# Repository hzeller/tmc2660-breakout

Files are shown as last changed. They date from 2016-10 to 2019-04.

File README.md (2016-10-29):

Breakout board for TMC2660
==========================

Breakout board with just the bare chip and necessary components around for
the [TMC2660][tmc2660-product] 2.8A stepper driver chip.
Detailed description found in the [datasheet][tmc2660-datasheet].



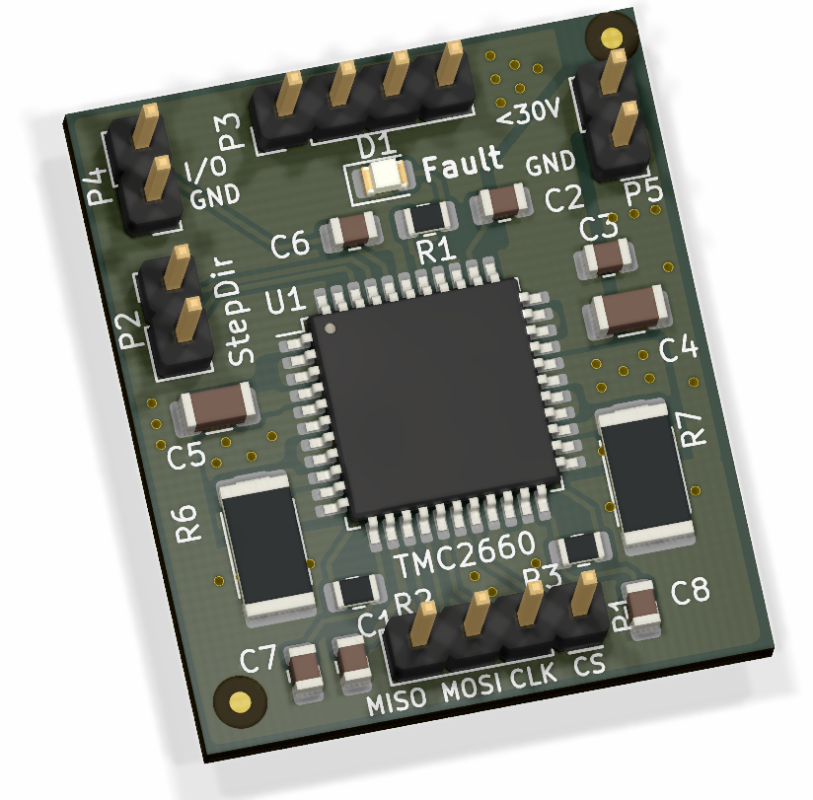
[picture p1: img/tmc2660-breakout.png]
Rendering


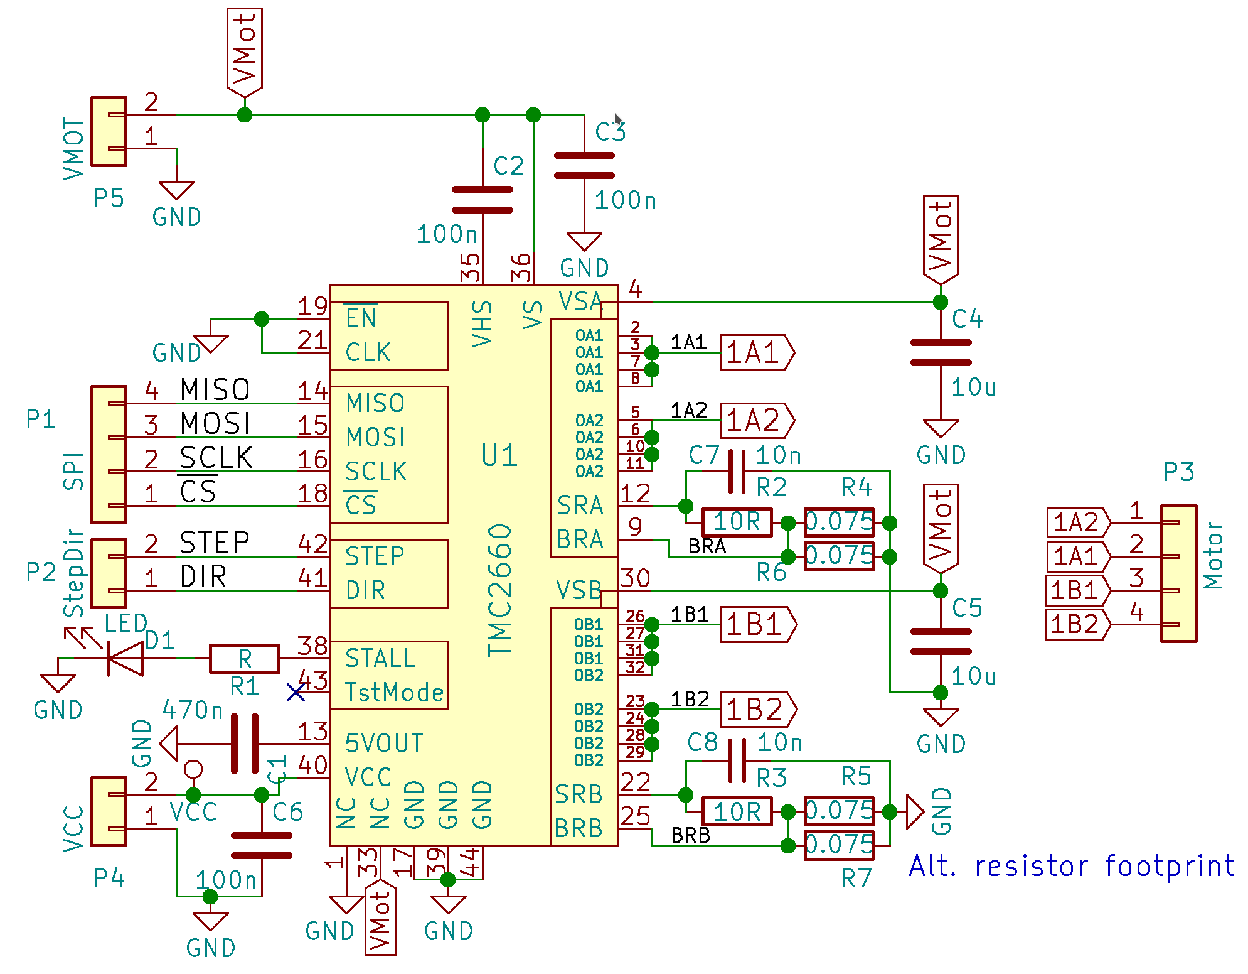
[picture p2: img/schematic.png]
Breakout schematic


[tmc2660-product]: http://www.trinamic.com/products/integrated-circuits/stepper-power-driver/tmc2660
[tmc2660-datasheet]: http://www.trinamic.com/_scripts/download.php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
[rendering]: ./img/tmc2660-breakout.png
[schematic]: ./img/schematic.png

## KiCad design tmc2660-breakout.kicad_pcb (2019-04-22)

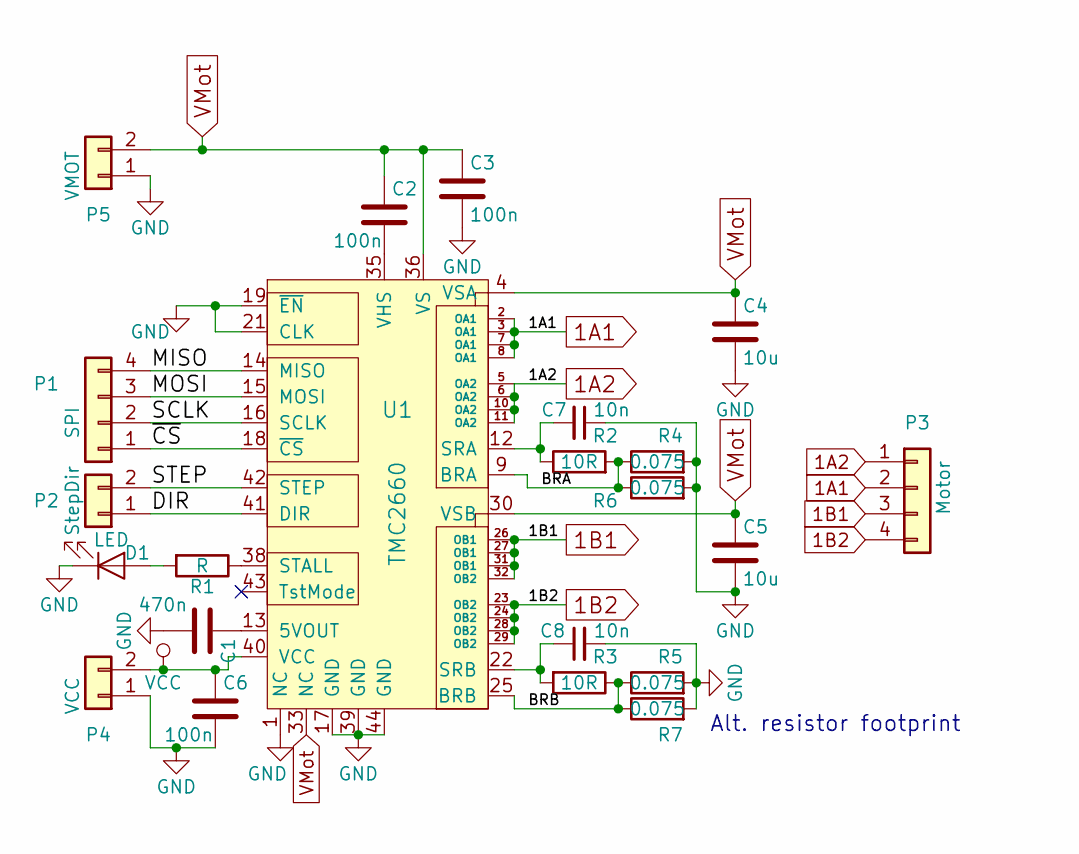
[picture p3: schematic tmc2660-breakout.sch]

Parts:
C1: 470n; C_0805_2012Metric
C2, C3, C6: 100n; C_0805_2012Metric
C4, C5: 10u; C_1206_3216Metric
C7, C8: 10n; C_0805_2012Metric
D1: LED; LED_0805_2012Metric
P1: SPI; PinHeader_1x04_P2.54mm_Vertical
P2: StepDir; PinHeader_1x02_P2.54mm_Vertical
P3: Motor; PinHeader_1x04_P2.54mm_Vertical
P4: VCC; PinHeader_1x02_P2.54mm_Vertical
P5: VMOT; PinHeader_1x02_P2.54mm_Vertical
R1: R; R_0805_2012Metric
R2, R3: 10R; R_0805_2012Metric
R4, R5: 0.075; R_1206_3216Metric
R6, R7: 0.075; R_2512_6332Metric
U1: TMC2660; LQFP-44_10x10mm_P0.8mm

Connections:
1A1: P3.2, U1.2 (OA1), U1.3 (OA1), U1.7 (OA1), U1.8 (OA1)
1A2: P3.1, U1.5 (OA2), U1.6 (OA2), U1.10 (OA2), U1.11 (OA2)
1B1: P3.3, U1.26 (OB1), U1.27 (OB1), U1.31 (OB1), U1.32 (OB2)
1B2: P3.4, U1.23 (OB2), U1.24 (OB2), U1.28 (OB2), U1.29 (OB2)
/BRA: R2.2, R4.1, R6.1, U1.9 (BRA)
/BRB: R3.1, R5.1, R7.1, U1.25 (BRB)
/DIR: P2.1, U1.41 (DIR)
/MISO: P1.4, U1.14 (MISO)
/MOSI: P1.3, U1.15 (MOSI)
/SCLK: P1.2, U1.16 (SCLK)
/STEP: P2.2, U1.42 (STEP)
/~CS: P1.1, U1.18 (~CS)
GND: C1.2, C3.2, C4.2, C5.2, C6.2, C7.1, C8.2, D1.1 (K), P4.1, P5.1, R4.2, R5.2, R6.2, R7.2, U1.1 (NC), U1.17 (GND), U1.19 (~EN), U1.21 (CLK), U1.39 (GND), U1.44 (GND)
unnamed: C1.1, U1.13 (5VOUT)
unnamed: C2.2, U1.35 (VHS)
unnamed: C7.2, R2.1, U1.12 (SRA)
unnamed: C8.1, R3.2, U1.22 (SRB)
unnamed: D1.2 (A), R1.2
unnamed: R1.1, U1.38 (STALL)
VCC: C6.1, P4.2, U1.40 (VCC)
VMot: C2.1, C3.1, C4.1, C5.1, P5.2, U1.4 (VSA), U1.30 (VSB), U1.33 (NC), U1.36 (VS)

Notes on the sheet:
Alt. resistor footprint

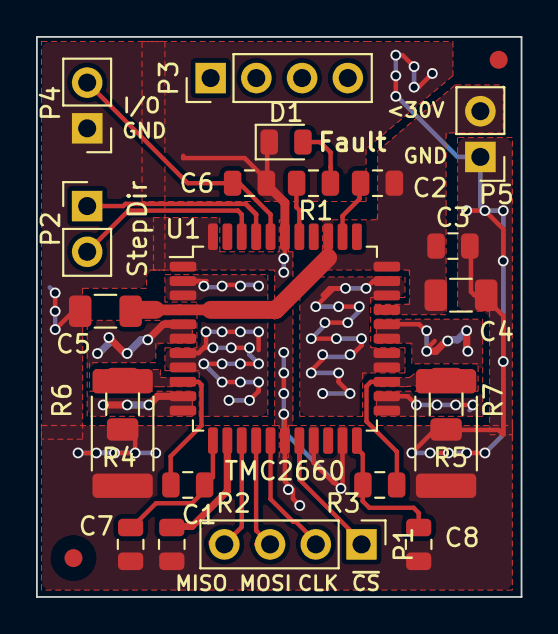
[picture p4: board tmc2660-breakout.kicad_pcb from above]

Board: 2 copper layers, 26.9 x 31.1 mm, 22 parts (0 on the bottom side), 21 nets.

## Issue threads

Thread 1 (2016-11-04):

BOM?

JBKingdon, 2016-11-04:
Hi,

Sorry for the beginner level question, but is there a parts list? I'm new to SMD and I'm having trouble figuring out what size capacitors and diode to order. The resistor sizes I read off the render of the board. I tried loading the project into kicad to see if I could find the footprint that way, but I couldn't find the .brd.

Many thanks for publishing this, it looks really useful!

salmansheikh, 2017-06-15:
Did you get it? I could install kicad and figure how to extract the parts list. I have it installed but dont really know how to use it. I actually like sort of, eagle cad even with its weird hotkeys. Hopefully autocad can fix those to more typical US key bindings like ctrl-c for copy, etc. Anyhow, i looked through one of the project text files and it gives the part sizes with reference numbers and values. I will parse by eye and post it if you have not resolved it. I ordered the boards from oshpark and they ship 6/23. Now i have to go online and order parts from digikey or mouser (cheaper parts and known lower shipping but digikey has lots more offerings).

JBKingdon, 2017-06-15:
Well, I ordered all the parts, so I guess I must have figured it out somehow, but I don't remember the details. I never did get around to trying it out though. One of the things I have to sort out is that I will need the chip enable signal, so I'll have to find a way of modifying the board a little.

hzeller, 2017-06-15:
This is really only a handful of components. All the smaller parts are 0805 size (including the LED), the current sense are 1206 or 2512 as alternative footprint. The capacitors for motor voltage are 1206 ceramic (but this is really only to buffer spikes, you should have a larger capacitor at the power input).

salmansheikh, 2017-06-27:
I just got my pcb boards from Oshpark today but forgot to order the parts before getting them :(
What is the value of R1. I got some xml file output from kicad and compiled the following list:

C4, C5 : 10uF 1206
C2, C3, C6: 100 nF 0805
C7, C8: 10 nF  0805
C1 470nF 0805
R2, R3, 10 ohm, 0805
R4-R7, 0.075, 1206
U1 TMC2660
and
R1 with no value? What should it be?

hzeller, 2017-06-27:
It is the resistor for the LED - so anything 150Ohm - 1kOhm should work.

hzeller, 2017-06-27:
Also have a look at the schematic - R4, R5 or R6, R7 are alternative footprints. Either 1206 or 2512.

salmansheikh, 2017-06-27:
how much wattage should R4-R7 be? 1/4 W good enough?

hzeller, 2017-06-27:
It is the shunt that has the motor current go through it, so you can calculate what wattage it needs.

Also, read my last comment, you only need two (not R4, R5, R6, R7).

salmansheikh, 2017-07-03:
What resistors would i need to drive one of these with your board? How to
calculate?

https://www.omc-stepperonline.com/hybrid-stepper-motor/nema-23-bipolar-18deg-19nm-269ozin-28a-32v-57x57x76mm-4-wires-23hs30-2804s.html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

hzeller, 2017-07-03:
The current depends on your application of course.

For current sensing and configuration please read the datasheet of the TMC2660.

salmansheikh, 2017-07-15:
I dont understand that formula for power, vsense and rsense. Do you have
any examples for the motor you designed the board for?

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

hzeller, 2017-07-15:
You have to initialize the chip via SPI, so there you configure the currents; so it is much nicer than other chips that require a potentiometer - it is already built-in. With the main sense resistors you only configure the ball-park.
As for the datasheet: As for any chip you want to use, you really need to read and understand it, there is not much I can help.

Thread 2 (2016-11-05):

Break out the ENN pin?

JBKingdon, 2016-11-05:
Hi,

Is there room to break out the ENN pin beside the step and dir pins? Having the mosfets always enabled is not ideal for some applications (3d printing is the one I'm thinking of).

hzeller, 2017-11-23:
This is now done in the follow-up project https://github.com/hzeller/quadrigotion

Closed 2017-11-23.

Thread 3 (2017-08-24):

Cannot open pcb file with Kicad 4.6

bogyxp, 2017-08-24:
I get an error while trying to open the pcb with Kicad 4.06.
Sais that the version the pcb was created with is newer than the one i have (which is actually the latest)
_Error loading board.
KiCad was unable to open this file, as it was created with a more recent version than the one you are running. To open it, you'll need to upgrade KiCad to a more recent version._
So i modified the first line of the pcb file and then i get an error: _PARSE ERROR: expecting learance,trace_width,(...) in input/source (...)_

Duckle29, 2017-12-14:
Get the nightly builds. Not even just to open this, but because they are much nicer :)

hzeller, 2017-12-14:
Also, you might be interested in https://github.com/hzeller/quadrigotion which is essentially my follow-up project.
(Also requires a nightly KiCAD build.)

nadavmatalon, 2018-04-29:
Hi hzeller,
I have version Kicad 4.0.7 installed but getting exactly the same error message as bogyxp above when trying to open the pcb design.
Any suggestion how to sort it out? (I'm a complete newbie to Kicad :-)

nadavmatalon, 2018-04-29:
Thanks for getting back to me.

Where did you get 5.0.0 from? All I see is the 4.0.7 on the [official website](http://kicad-pcb.org/download/osx/)

Also, are you using Windows or MacOS? (I'm using the latter so maybe that's the problem)

nadavmatalon, 2018-04-29:
Btw, forgot to mention, it makes little sense that something compiled in 2016 won't open on Kicad versions that came out much later (be it 4.0.7 or 5.0.0).

Any chance you might be able to upload the most minimal version of the schematics & board layout without all the extras and perhaps that will open correctly? (sorry, not sure what the correct terms are in Kicad)

hzeller, 2018-04-29:
I am using Linux and I just compiled it from source.
There are no extras, this is just the minimal version. Given that this is 2 years old, you might need to do a little adjustments with libraries.

nadavmatalon, 2018-04-29:
Ok, thanks.

nadavmatalon, 2018-04-29:
Sorry, one last question if I may: could you please tell me what were the dimensions of the vias you used for this board (drill size & overall diameter)?

besi, 2020-06-03:
Since this is now two years old I would suggest to close the issue.

hzeller, 2020-06-03:
Also, it should be fixed with https://github.com/hzeller/tmc2660-breakout/commit/c7a9a22456cac7ffe0ac24dff0842ad8f5f2ad77

Closed 2020-06-03.

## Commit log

2015-12-14 o Start tracking.
    [tmc2660-breakout.kicad_pcb, tmc2660-breakout.sch]
2015-12-15 o little tweaks.
    [tmc2660-breakout.kicad_pcb, tmc2660-breakout.sch]
2015-12-18 o First fully placed and routed.
    [tmc2660-breakout.kicad_pcb, tmc2660-breakout.sch]
2015-12-18 o Add makefile to create fab files.
    [tmc2660-breakout.kicad_pcb]
2015-12-18 o Better placement of git version.
    [tmc2660-breakout.kicad_pcb]
2015-12-18 o Text placement tweaks.
    [tmc2660-breakout.kicad_pcb]
2015-12-18 o Better labelling.
    [tmc2660-breakout.kicad_pcb]
2015-12-18 o Unhide displayed signals.
    [tmc2660-breakout.kicad_pcb]
2015-12-18 o Add basic readme. o Add gerbers.
2015-12-19 o More ground copper all the way around.
    [tmc2660-breakout.kicad_pcb]
2015-12-19 o Top ground pin: thicker trace, now better connecting to parts of the ground plane.
    [tmc2660-breakout.kicad_pcb]
2015-12-19 o Turn around VCC/GND connector so that it has the same direction as the VMOT connector. Less possibly dangerous confusion ...
    [tmc2660-breakout.kicad_pcb]
2015-12-19 o Add Fiducials.
    [tmc2660-breakout.kicad_pcb]
2016-01-05 o Add schematic image.
    [tmc2660-breakout.sch]
2016-01-06 o Miso/Mosi was swapped.
    [tmc2660-breakout.kicad_pcb, tmc2660-breakout.sch]
2016-01-07 o Add alternative footprint for shunt (2512 is more appropriate)
    [tmc2660-breakout.kicad_pcb, tmc2660-breakout.sch]
2016-01-07 o Widen the other 1206 pad to match the 2512 pad to avoid tombstoning
    [tmc2660-breakout.kicad_pcb, tmc2660-breakout.sch]
2016-01-07 o Add optional filter caps for sense input. o Connect CLK input to GND to enable internal clock. o Fix typo in sense decoupling resistor (10k -> 10R)
    [tmc2660-breakout.kicad_pcb, tmc2660-breakout.sch]
2016-10-28 o Update gerbers with the latest version.
2016-10-29 o Make sure that only the version of the PCB file is used to generate the git string.
2016-11-13 o smallish alignments
    [tmc2660-breakout.kicad_pcb]
2016-11-13 o Label some previously anonymous nets (e.g. Step/Dir).
    [tmc2660-breakout.kicad_pcb, tmc2660-breakout.sch]
2019-04-22 Use current KiCAD 5.x libraries.
    [tmc2660-breakout.kicad_pcb, tmc2660-breakout.sch]
